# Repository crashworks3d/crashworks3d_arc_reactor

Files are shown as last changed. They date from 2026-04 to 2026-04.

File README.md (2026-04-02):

# CW3D Arc Reactor

**Iron Man–inspired NeoPixel arc reactor built on an ESP32-C3 SuperMini running CircuitPython.**

Created by [Crash Works 3D](https://crashworks3d.com) for a hands-on panel at [Compass Community Collaborative School](https://compassfortcollins.org/) — a project-based learning school in Fort Collins, CO serving grades 6–12.

Students assemble a pre-printed shell, seat the pre-wired NeoPixel rings, fasten three screws, and plug in USB-C. The reactor glows. Then they learn why.

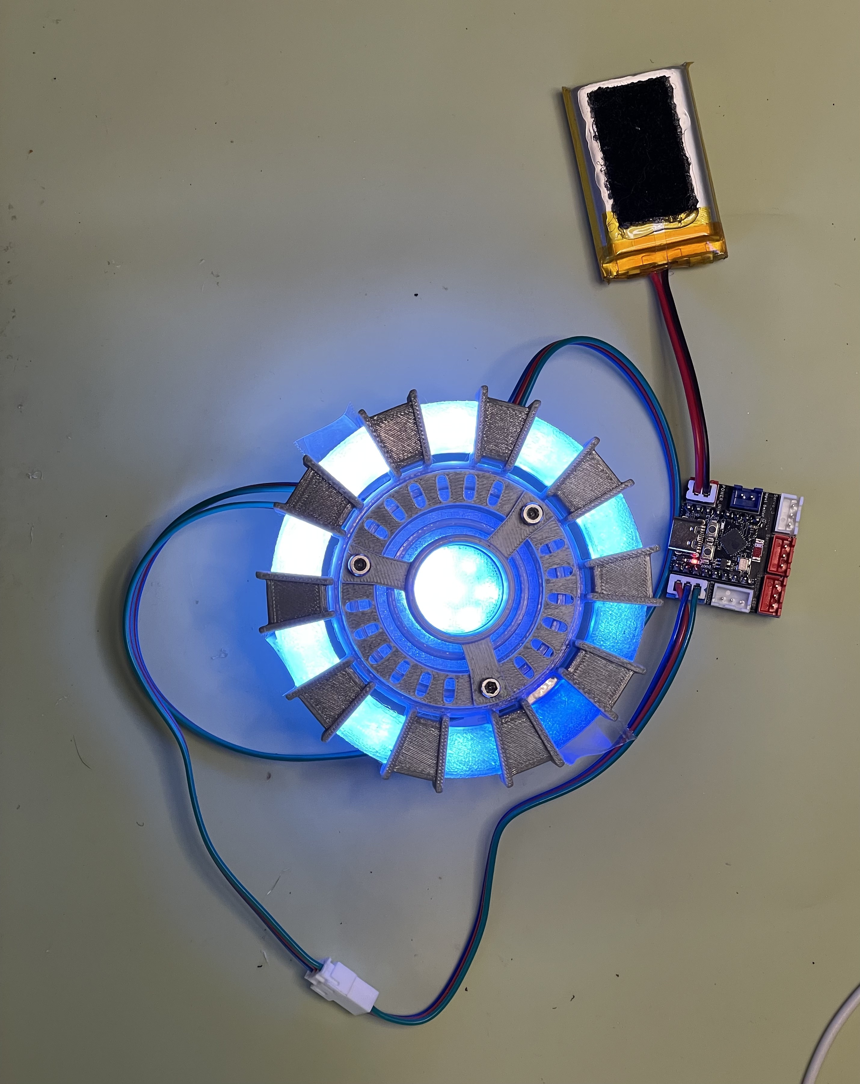
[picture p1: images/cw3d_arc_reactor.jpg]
CW3D Arc Reactor


---

## What's in This Repo

```
src/
  code.py             CircuitPython arc reactor animation (teaching edition)
  blink_test.py       Quick single-pixel sanity check

scripts/
  flash.sh            One-command flash tool (macOS/Linux — bash)
  flash.py            One-command flash tool (macOS/Linux/Windows — Python)

stl/
  crystal_ring.stl          Outer diffuser — seats 24-LED NeoPixel ring
  main_crystal_bottom.stl   Inner diffuser — seats 7-LED center component
  main_crystal_top.stl      Top diffuser cap
  main_crystal_enclosure.stl  Crystal shell enclosure
  upper_grid.stl            Decorative outer shell
  lower_grid_and_caps.stl   Back plate + end caps

docs/
  batch-flash-log.md                    Per-board flash & test checklist
```

---

## Hardware (Per Kit)

| Part | Qty | Notes |
|---|---|---|
| ESP32-C3 SuperMini (black PCB) | 1 | ~$3–4, AliExpress or Amazon |
| WS2812b 24-LED NeoPixel ring | 1 | Outer crystal — AliExpress or Adafruit |
| WS2812b 7-LED NeoPixel component | 1 | Center crystal — AliExpress |
| 22–24 AWG stranded wire | short lengths | Pre-soldered directly |
| M3×20mm screws | 3 | Main shell assembly |
| M3×12mm screws | 3 | Crystal enclosure (`main_crystal_enclosure.stl`) |
| M2×5mm self-tapping screws | 2 | Secures 7-LED jewel in `main_crystal_bottom.stl` |

> **Drill note:** Due to print scaling, screw holes may need to be bored out with a **7/64" drill bit** before M3 screws will fit cleanly.

**Estimated cost per kit: ~$9–14** (3D print filament not included)

### Wiring

The two NeoPixel components are **daisy-chained** on a single data line. The 7-LED center is first in the chain:

```mermaid
graph LR
    USB[USB-C Power]

    subgraph ESP32["ESP32-C3 SuperMini"]
        VBUS[5V / VBUS]
        GND[GND]
        GPIO2[GPIO2]
    end

    subgraph CENTER["7-LED NeoPixel Center (pixels 0–6)"]
        C_VCC[VCC]
        C_GND[GND]
        C_DIN[DATA IN]
        C_DOUT[DATA OUT]
    end

    subgraph OUTER["24-LED NeoPixel Ring (pixels 7–30)"]
        O_VCC[VCC]
        O_GND[GND]
        O_DIN[DATA IN]
    end

    USB -->|5V| VBUS
    USB -->|GND| GND

    VBUS -->|5V| C_VCC
    VBUS -->|5V| O_VCC
    GND  -->|GND| C_GND
    GND  -->|GND| O_GND

    GPIO2  -->|DATA| C_DIN
    C_DOUT -->|CHAIN| O_DIN
```

| Signal | From | To |
|---|---|---|
| 5V (USB VBUS) | ESP32-C3 5V | 7-LED VCC + 24-LED VCC |
| GND | ESP32-C3 GND | 7-LED GND + 24-LED GND |
| DATA | ESP32-C3 GPIO2 | 7-LED center DATA IN |
| CHAIN | 7-LED center DATA OUT | 24-LED ring DATA IN |

Pixel indices: 0–6 = center cluster, 7–30 = outer ring (31 total).

> **Why GPIO2?** Avoids the GPIO8 conflict on some ESP32-C3 variants and is safe for RMT-based NeoPixel signaling.

### Electronics Concepts

**Microcontroller — ESP32-C3 SuperMini**
A microcontroller is a tiny computer on a single chip. Unlike a laptop, it runs one program (`code.py`) on an endless loop. The ESP32-C3 has GPIO (General Purpose Input/Output) pins you control directly from code — GPIO2 is the pin that sends the LED data signal.

**Addressable LEDs — WS2812b**
Each LED in this project is a WS2812b: a standard RGB LED with a tiny controller chip built inside the package. The chip understands a single-wire serial protocol — the microcontroller sends a stream of bits, each LED reads exactly 24 bits (8 bits each for red, green, blue), then passes the rest of the stream down to the next LED. One wire from GPIO2 controls all 31 pixels.

**Power — VCC and GND**
Every circuit needs two power connections: VCC (positive, 5V here from USB-C) and GND (ground, 0V). All components share a single power rail and common ground. The `BRIGHTNESS = 0.35` cap in code keeps current draw safe for a standard USB port.

**The Daisy Chain**
The 7-LED center and 24-LED ring are wired in series on the data line. The first LED reads its 24-bit color instruction and forwards the rest of the stream to the next, all the way down the chain. Each full animation frame sends 31 × 24 = 744 bits.

### What This Circuit Teaches

| Concept | Component | Learning Moment |
|---|---|---|
| Microcontrollers | ESP32-C3 SuperMini | A single chip that runs your code — no OS, no distractions |
| GPIO pins | GPIO2 → LED DATA IN | Code talks to the physical world through numbered pins |
| Power rails | VCC (5V) + GND | Every circuit needs + and − power connections |
| Voltage | USB-C → 5V | Electricity has "pressure" — USB delivers a safe, standard 5V |
| Addressable LEDs | WS2812b | Each LED has its own controller chip — 24 bits sets RGB color |
| Serial data protocol | Single wire, 744 bits/frame | One wire with clever timing controls all 31 LEDs |
| Daisy chaining | DATA OUT → DATA IN | LEDs pass data down the line like a telephone game |
| Current limiting | `BRIGHTNESS = 0.35` | More pixels + brighter = more current; cap protects the USB port |

---

## 3D Printing

All STL files are in the `stl/` folder. These are remixed from [aelkaim's arc reactor on Printables](https://www.printables.com/model/233261-iron-man-arc-reactor) to accommodate the full dual-ring electronics.

| Part | Material | Infill |
|---|---|---|
| Crystal ring, bottom, top, enclosure | Transparent PETG or PLA | 100% |
| Upper grid, lower grid + caps | Silk Silver PLA | Standard |

Print crystal/diffuser parts at **100% infill** — lower infill reduces light diffusion.
Target outer diameter: **~65mm** to seat the 24-LED ring.

---

## Firmware Setup

### Requirements

- Python 3.8+
- [esptool](https://github.com/espressif/esptool) — `pip install esptool`

### Step 1 — Download the CircuitPython firmware

Download the `.bin` file for **Maker Go ESP32C3 Supermini** from:
[circuitpython.org/board/makergo_esp32c3_supermini/](https://circuitpython.org/board/makergo_esp32c3_supermini/)

Place it in the `bin/` folder at the project root with this exact filename:

```
bin/adafruit-circuitpython-makergo_esp32c3_supermini-en_US-10.1.4.bin
```

> The `bin/` folder is git-ignored. You must download the firmware manually — it is not included in this repo.

### Step 2 — Flash

Two flash scripts are provided. Both do the same thing — choose based on your OS:

**macOS / Linux** (bash):
```bash
bash scripts/flash.sh [port]
```

**macOS / Linux** (Python):
```bash
python3 scripts/flash.py [port]
```

**Windows** (Python):
```bash
python scripts/flash.py [port]
```

Default ports if none is specified:

| OS | Default port |
|---|---|
| macOS | `/dev/cu.usbmodem14301` |
| Linux | `/dev/ttyUSB0` |
| Windows | `COM3` |

The script will prompt you to put the board in download mode (BOOT + RESET), then:

1. Erases flash
2. Writes CircuitPython firmware
3. Builds a FAT12 filesystem image containing `code.py` and `lib/neopixel.mpy`
4. Writes the filesystem to the ESP32-C3 user partition

After flashing, unplug and reconnect to a USB-C power source — the animation starts immediately.

> **Note on the ESP32-C3 and USB:** The ESP32-C3 SuperMini uses an internal USB Serial/JTAG controller (no USB OTG). The CIRCUITPY drive does **not** appear on the host computer. Files are deployed by building a FAT12 image and flashing it directly. Use [Thonny](https://thonny.org/) for interactive REPL access.

### Manual Installation (Thonny)

1. Flash CircuitPython using the [Adafruit web installer](https://circuitpython.org/board/makergo_esp32c3_supermini/)
2. Open Thonny → connect to the ESP32-C3
3. Copy `src/code.py` → `/code.py` on device
4. Copy `neopixel.mpy` → `/lib/neopixel.mpy` on device
5. Press RESET — animation starts

---

## The Code

[`src/code.py`](src/code.py) is intentionally written as a **teaching document**. Every section has a comment explaining the concept in plain language for a middle-school audience.

### What It Teaches

| Concept | Code |
|---|---|
| Libraries | `import board`, `import neopixel`, `import math` |
| Variables / constants | `BRIGHTNESS`, `SLEEP_MS`, `SWEEP_RATE`, … |
| Objects | `neopixel.NeoPixel(...)`, `auto_write=False` |
| Functions | `def arc_reactor(pixels, t):` |
| Swappable behavior | `animate = arc_reactor` → `animate = rainbow_chase` |
| Sine wave / math | `(math.sin(t * OUTER_SPEED + i * PHASE_STEP) + 1) / 2` |
| Loops + modulo | `CENTER_COUNT + int(t * SWEEP_RATE) % OUTER_COUNT` |
| RGB color mixing | `(r, g, b)` tuples, values 0–255 |
| Color wheel helper | `colorwheel(pos)` — maps 0–255 to a rainbow color |
| Two independent zones | `range(CENTER_COUNT)` vs `range(CENTER_COUNT, NUM_PIXELS)` |
| Frame buffering | `pixels.show()` called once per frame |
| Frame pacing | `time.sleep(SLEEP_MS / 1000)` |

---

## Troubleshooting

### Hardware

**No LEDs light up after plugging in USB-C**
- Confirm the USB-C cable is a data+power cable (some cables are charge-only)
- Try a different USB-C port or charger — the board needs at least 500 mA
- Check that the ESP32-C3 power LED is on; if not, the board isn't receiving power
- Verify all three solder joints on the ESP32-C3 (5V, GND, GPIO2)

**Only the center LEDs light up (outer ring is dark)**
- The daisy-chain connection between the 7-LED center DATA OUT and the 24-LED ring DATA IN may be broken
- Inspect the solder joint or wire connection between the two components
- Confirm pixel index constants in `code.py` match your chain order (`CENTER_COUNT = 7`)

**Only a few pixels in the ring light up or the colors look wrong**
- A broken DATA wire causes all downstream LEDs to go dark or stick to the last received color
- Check the DATA OUT → DATA IN connection at each link in the chain
- Try reducing `BRIGHTNESS` to rule out a power issue on longer chains

**One pixel is always bright white or shows garbage color**
- That LED's internal controller chip may be damaged (common from static or overvoltage)
- Set that pixel to `(0, 0, 0)` in code as a workaround; the rest of the chain is unaffected

**Board gets warm and LEDs are dim or flicker**
- USB port may be current-limited (common on older laptop ports)
- Reduce `BRIGHTNESS` in `code.py` — try `0.2` as a starting point
- Use a USB-C phone charger instead of a computer port

**Screws won't thread into the printed holes**
- Print tolerances vary — bore out M3 holes with a **7/64" (2.8 mm) drill bit**
- For M2 holes in `main_crystal_bottom.stl`, use a **5/64" (2 mm) drill bit**

---

### Software / Flashing

**`python: command not found` on macOS or Linux**
- macOS ships `python3`, not `python` — use `python3 scripts/flash.py`
- Verify Python is installed: `python3 --version`

**`No module named esptool`**
- Install esptool: `pip install esptool` (or `pip3 install esptool`)
- Confirm the install succeeded: `esptool.py version` or `python3 -m esptool version`

**`A fatal error occurred: Failed to connect to ESP32-C3`**
- The board was not put into download mode before flashing
- Hold **BOOT**, tap **RESET**, release **BOOT** — then immediately re-run the script
- Try a slower baud rate by editing `BAUD = '115200'` in `flash.py`
- Try a different USB cable (data+power required)

**Wrong port error (e.g., `No such file or directory: /dev/cu.usbmodem14301`)**
- Find your port: macOS/Linux: `ls /dev/cu.*` or `ls /dev/tty.*`; Windows: Device Manager → Ports
- Pass the port explicitly: `python3 scripts/flash.py /dev/cu.usbmodem12345`

**Flash succeeds but the board shows no animation after reset**
- Verify `code.py` and `lib/neopixel.mpy` exist in the project (`src/` and `bundle/`)
- Check the paths printed by `flash.py` — it validates all three files before proceeding
- Re-run the full flash sequence to rewrite the filesystem image

**`ImportError: no module named 'neopixel'` in CircuitPython REPL**
- The `neopixel.mpy` file was not written to the filesystem correctly
- Re-run `flash.py` — Step 3 rebuilds and Step 4 rewrites the FAT12 image

**Thonny can't connect to the board**
- CircuitPython's USB Serial/JTAG may need a moment after reset — wait 2–3 seconds and retry
- In Thonny: Tools → Options → Interpreter → select **CircuitPython (generic)** and the correct port
- On Linux, add your user to the `dialout` group: `sudo usermod -a -G dialout $USER` (requires logout/login)

---

## Credits

- **Original 3D model:** [aelkaim on Printables](https://www.printables.com/model/233261-iron-man-arc-reactor) / [Thingiverse mirror](https://www.thingiverse.com/thing:2799642)
- **CircuitPython:** [Adafruit](https://circuitpython.org/)
- **Designed and remixed by:** [Crash Works 3D](https://crashworks3d.com)

---

## License

Firmware, scripts, and documentation in this repository are licensed under the [Crash Works 3D Software License Agreement](LICENSE.md) — personal, non-commercial use only. See `LICENSE.md` for full terms.

3D models in `stl/` are derived from [aelkaim's arc reactor](https://www.printables.com/model/233261-iron-man-arc-reactor) and are subject to the original model's license terms.

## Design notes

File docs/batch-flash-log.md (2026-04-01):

# Batch Flash Log — CW3D Arc Reactor
# STORY-003: Batch Flash & Test

## Firmware Reference

| File | MD5 |
|---|---|
| `adafruit-circuitpython-makergo_esp32c3_supermini-en_US-10.1.4.bin` | `b579130c38921cbfe2ddc7822f914dc4` |
| `src/code.py` | `f2861452148cccde0ecfc5ea1ee4c164` |
| `neopixel.mpy` (bundle 10.x-mpy-20260401) | — |

Flash command: `bash scripts/flash.sh`

---

## Board Log

| Board # | Firmware Flashed | CIRCUITPY Mounted | Files Copied | Power-On Test | Soak Test (2 min) | Notes | Disposition |
|---|---|---|---|---|---|---|---|
| 01 | ☐ / ☐ double | ☐ | ☐ | ☐ PASS / ☐ FAIL | ☐ PASS / ☐ FAIL | | Kit bag |
| 02 | ☐ / ☐ double | ☐ | ☐ | ☐ PASS / ☐ FAIL | ☐ PASS / ☐ FAIL | | Kit bag |
| 03 | ☐ / ☐ double | ☐ | ☐ | ☐ PASS / ☐ FAIL | ☐ PASS / ☐ FAIL | | Kit bag |
| 04 | ☐ / ☐ double | ☐ | ☐ | ☐ PASS / ☐ FAIL | ☐ PASS / ☐ FAIL | | Kit bag |
| 05 | ☐ / ☐ double | ☐ | ☐ | ☐ PASS / ☐ FAIL | ☐ PASS / ☐ FAIL | | Kit bag |
| 06 | ☐ / ☐ double | ☐ | ☐ | ☐ PASS / ☐ FAIL | ☐ PASS / ☐ FAIL | | Kit bag |
| 07 | ☐ / ☐ double | ☐ | ☐ | ☐ PASS / ☐ FAIL | ☐ PASS / ☐ FAIL | | Kit bag |
| 08 | ☐ / ☐ double | ☐ | ☐ | ☐ PASS / ☐ FAIL | ☐ PASS / ☐ FAIL | | Kit bag |
| 09 | ☐ / ☐ double | ☐ | ☐ | ☐ PASS / ☐ FAIL | ☐ PASS / ☐ FAIL | | Kit bag |
| 10 | ☐ / ☐ double | ☐ | ☐ | ☐ PASS / ☐ FAIL | ☐ PASS / ☐ FAIL | | Kit bag |
| 11 | ☐ / ☐ double | ☐ | ☐ | ☐ PASS / ☐ FAIL | ☐ PASS / ☐ FAIL | | **Spare 1** |
| 12 | ☐ / ☐ double | ☐ | ☐ | ☐ PASS / ☐ FAIL | ☐ PASS / ☐ FAIL | | **Spare 2** |

---

## Summary

- Boards flashed: — / 12
- Boards passed: — / 12
- Double-flashes required: —
- Hardware failures: —
- Replacements made: —

---

## Edge Case Notes

**Board fails to flash:** Re-run `bash scripts/flash.sh`. Check USB cable is data-capable.
**Animation missing after flash:** Verify board booted (tap RESET without BOOT after flashing).
**Dark pixel(s):** Hardware fault — set aside, use spare.
**Freeze during soak:** Do not ship — set aside, use spare.

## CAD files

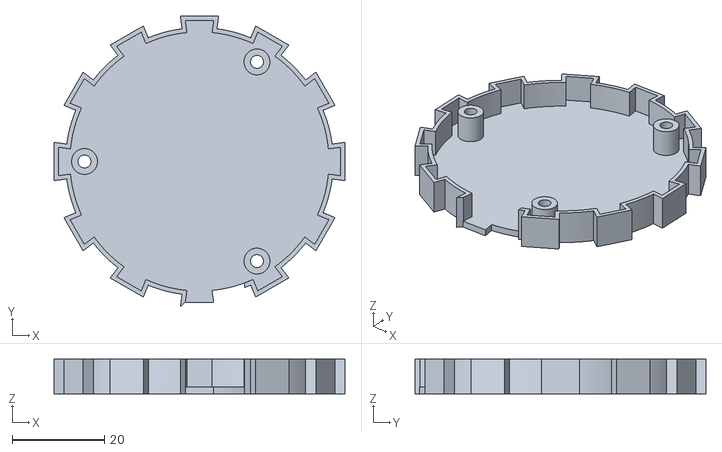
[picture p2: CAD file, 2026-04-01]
stl/main_crystal_enclosure.stl
63.2 x 63.2 x 7.50

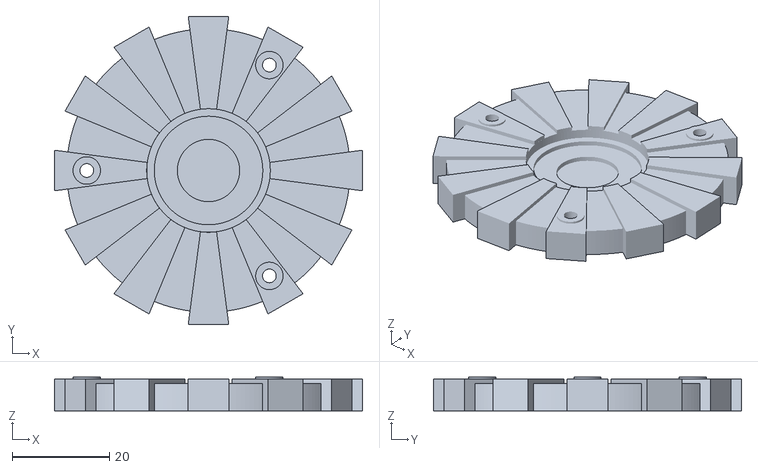
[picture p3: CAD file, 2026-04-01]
stl/main_crystal_top.stl
63.2 x 63.2 x 6.91

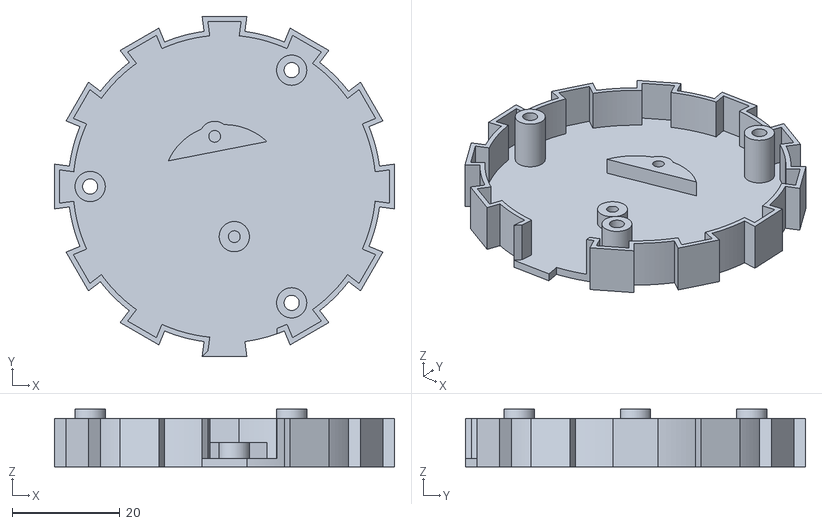
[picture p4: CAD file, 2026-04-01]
stl/main_crystal_bottom.stl
63.2 x 63.2 x 10.7

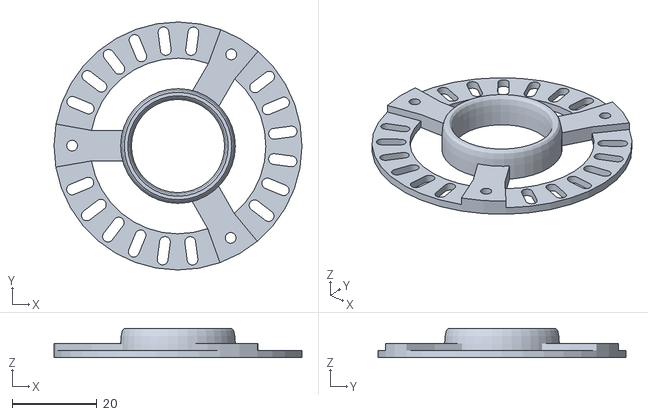
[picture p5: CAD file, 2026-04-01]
stl/upper_grid.stl
58.5 x 58.5 x 6.89

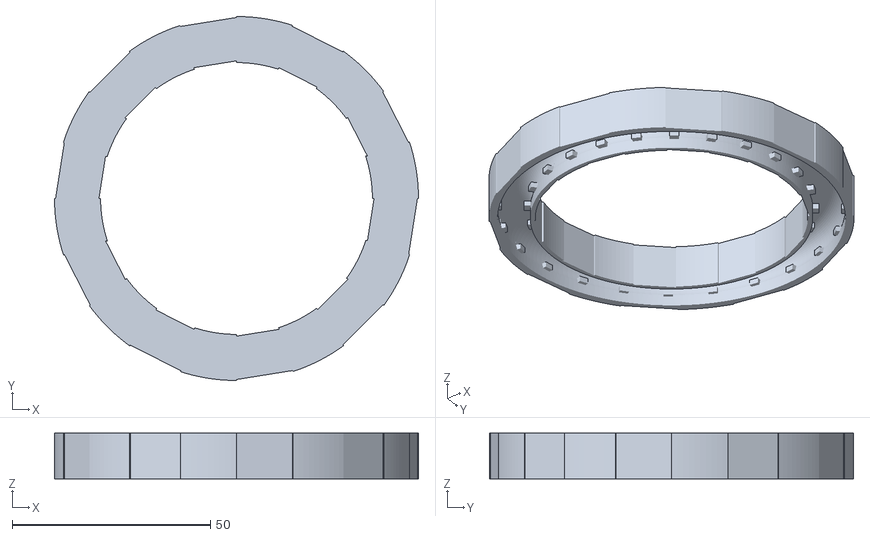
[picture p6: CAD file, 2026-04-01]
stl/crystal_ring.stl
91.7 x 91.7 x 11.5

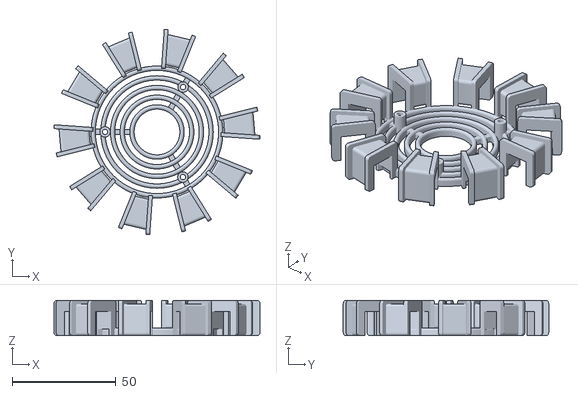
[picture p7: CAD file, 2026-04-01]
stl/lower_grid_and_caps.stl
99.1 x 98.8 x 16.9

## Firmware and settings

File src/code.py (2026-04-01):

# Arc Reactor -- CW3D / Compass School  (CircuitPython 10.x)

# Libraries: pre-written code that saves us from scratch.
import board
import math
import time
import neopixel

# Constants: change one number here to change the whole animation.
PIXEL_PIN    = board.IO2  # data pin wired to the LED ring
NUM_PIXELS   = 31         # 7-LED center + 24-LED ring = 31 total
CENTER_COUNT = 7          # pixels in the center cluster (first in chain)
OUTER_COUNT  = 24         # pixels in the outer ring
BRIGHTNESS   = 0.35       # global brightness; max 0.4 to save power
SLEEP_MS     = 20         # pause between frames; lower = faster
SWEEP_RATE   = 4.0        # how fast the leading pixel rotates
OUTER_SPEED  = 1.5        # how fast the outer ring breathes
PHASE_STEP   = 0.4        # phase shift between neighboring pixels
CENTER_SPEED = 3.0        # center pulses faster than the ring

# Object: NeoPixel wraps all 31 LEDs in one variable.
# auto_write=False means we control exactly when LEDs update.
pixels = neopixel.NeoPixel(
    PIXEL_PIN, NUM_PIXELS,
    brightness=BRIGHTNESS, auto_write=False)


# Function: one frame of the arc reactor animation.
# pixels = the LED strip object  |  t = current time in seconds
# To swap animations, write a function with the same signature:
#   def my_animation(pixels, t): ...
# then change: animate = my_animation
def arc_reactor(pixels, t):

    # Leading pixel index, stepping around the ring each frame.
    sweep = CENTER_COUNT + int(t * SWEEP_RATE) % OUTER_COUNT

    for i in range(CENTER_COUNT, NUM_PIXELS):
        # Sine wave: smooth 0.0-to-1.0 value, like breathing.
        s = (math.sin(t * OUTER_SPEED + i * PHASE_STEP) + 1) / 2
        if i == sweep:
            pixels[i] = (180, 220, 255)  # bright highlight pixel
        else:
            # R, G, B: three numbers (0-255) mix to make any color.
            r = int(80 * s)
            g = int(160 * s)
            b = int(60 + 195 * s)
            pixels[i] = (r, g, b)

    # Center pulse: faster sine, floor at 0.5 so it stays bright.
    cs = 0.5 + 0.5 * (math.sin(t * CENTER_SPEED) + 1) / 2
    cr = int(160 + 60 * cs)
    cg = int(200 + 40 * cs)
    for i in range(CENTER_COUNT):
        pixels[i] = (cr, cg, 255)  # all 7 center pixels same color


# Helper: converts a 0-255 position into an (r, g, b) rainbow color.
# Imagine a color wheel — 0=red, 85=green, 170=blue, 255=back to red.
# No extra libraries needed; pure math using only multiplication.
def colorwheel(pos):
    pos = pos % 256
    if pos < 85:
        return (255 - pos * 3, pos * 3, 0)       # red → green
    if pos < 170:
        pos -= 85
        return (0, 255 - pos * 3, pos * 3)        # green → blue
    pos -= 170
    return (pos * 3, 0, 255 - pos * 3)            # blue → red


# Function: one frame of a rainbow chase animation.
# Every pixel gets a different hue; the whole rainbow shifts each
# frame so it appears to chase around the strip.
def rainbow_chase(pixels, t):

    # offset moves the rainbow forward a little each frame.
    offset = int(t * 50) % 256

    for i in range(NUM_PIXELS):
        # Space hues evenly around the wheel, then shift by offset.
        hue = (offset + i * 256 // NUM_PIXELS) % 256
        pixels[i] = colorwheel(hue)


# Swap this line to use a different animation function.
# Try: animate = rainbow_chase
animate = arc_reactor

t = 0.0  # time counter; grows by one frame each loop

# Main loop: runs forever - this IS the animation.
while True:
    animate(pixels, t)           # fill the pixel buffer for this frame
    pixels.show()                # send the full buffer to LEDs at once
    t += SLEEP_MS / 1000         # advance the time counter one frame
    time.sleep(SLEEP_MS / 1000)  # /1000 converts ms to seconds

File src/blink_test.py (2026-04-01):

# blink_test.py — STORY-001 Hardware Validation
# CW3D Arc Reactor Panel — Compass School
#
# PURPOSE: Validate the complete hardware chain before any animation work.
#          This is NOT the final code.py — it is a diagnostic only.
#
# USAGE:
#   1. Copy this file to the root of the CIRCUITPY drive as "code.py"
#   2. Open serial console (Mu / Thonny / screen) and confirm no import errors
#   3. Watch the board: all 31 pixels should cycle blue → off → blue → off
#   4. Confirm BOTH zones light up:
#        Pixels  0-23 = 24-LED outer ring
#        Pixels 24-30 = 7-LED center cluster
#   5. If all 31 pixels respond cleanly → STORY-001 acceptance criteria met
#
# WIRING REMINDER:
#   ESP32-C3 GPIO2 → 24-LED ring DATA IN
#   24-LED ring DATA OUT → 7-LED center DATA IN
#   Shared 5V (USB VBUS) and GND to both components

import board
import neopixel
import time

NUM_PIXELS = 31       # 24 outer ring + 7 center cluster
PIXEL_PIN = board.IO2 # Single data line — head of the daisy chain
BRIGHTNESS = 0.2      # Keep low during USB-bus-powered bench test

pixels = neopixel.NeoPixel(
    PIXEL_PIN, NUM_PIXELS, brightness=BRIGHTNESS, auto_write=False
)

print("CW3D Arc Reactor — blink test starting")
print(f"Driving {NUM_PIXELS} pixels on {PIXEL_PIN}")

while True:
    pixels.fill((0, 0, 255))  # All pixels blue ON
    pixels.show()
    time.sleep(1)

    pixels.fill((0, 0, 0))    # All pixels OFF
    pixels.show()
    time.sleep(1)

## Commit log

2026-04-01 Initial commit — CW3D Arc Reactor firmware, STL files, and flash script
    - CircuitPython arc reactor animation (teaching edition) for ESP32-C3 SuperMini
    - Dual-zone NeoPixel animation: 7-LED center (pixels 0–6) + 24-LED outer ring (pixels 7–30)
    - One-command batch flash script (esptool + FAT12 image builder)
    - 6-part 3D printable arc reactor STL files (CW3D remixed from aelkaim original)
    - Batch flash log and per-board test checklist
    [crystal_ring.stl, lower_grid_and_caps.stl, main_crystal_bottom.stl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]
2026-04-01 Add function encapsulation and rainbow chase animation
    - Wrap arc reactor animation in arc_reactor(pixels, t) function
    - Add colorwheel(pos) helper — pure integer math, no extra libraries
    - Add rainbow_chase(pixels, t) as a swappable alternative animation
    - animate = arc_reactor is the single line to change effects
    - Update README teaching table with Functions, Swappable behavior,
    and Color wheel helper concepts
    [code.py]
2026-04-01 Update hardware assembly details with accurate screw specs
    - Main shell: 3x M3x20mm screws
    - Crystal enclosure: 3x M3x12mm screws
    - 7-LED jewel mount: 2x M2x5mm self-tapping screws
    - Add 7/64 inch drill bit note for M3 hole fit due to print scaling
2026-04-02 Expand electronics education content in README
    - Add Electronics Concepts section covering microcontrollers,
    WS2812b addressable LEDs, power rails, and daisy chaining
    - Add What This Circuit Teaches table (8 concepts)
    - Minor intro wording update
2026-04-02 Fix flash.py esptool detection and python3 docs
    - Find esptool in PATH first (esptool/esptool.py), fall back to
    python -m esptool; fixes 'No module named esptool' when esptool
    is installed under a different Python than sys.executable
    - Print resolved esptool path at startup for easier diagnostics
    - README and script docstring updated: use python3 on macOS/Linux
